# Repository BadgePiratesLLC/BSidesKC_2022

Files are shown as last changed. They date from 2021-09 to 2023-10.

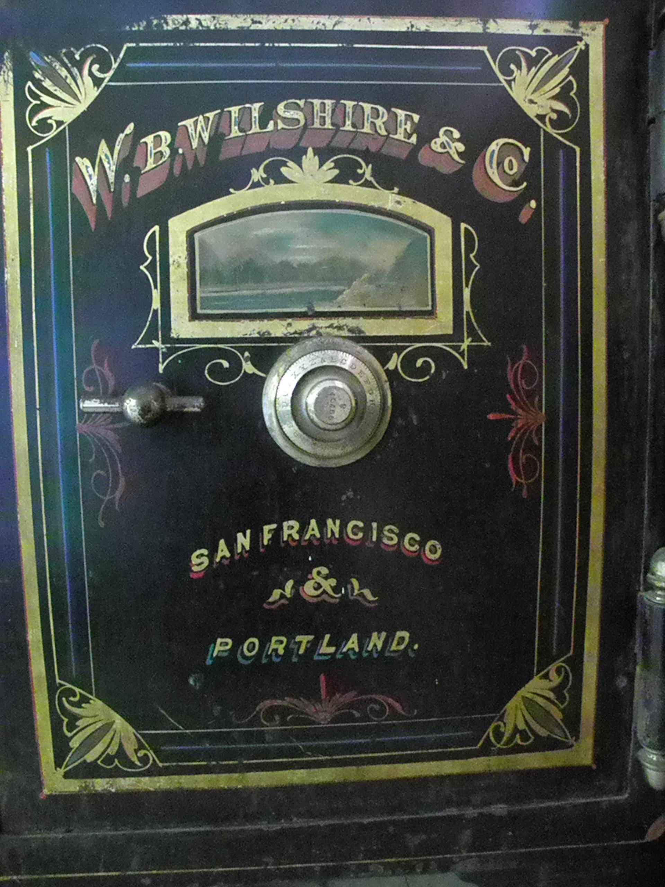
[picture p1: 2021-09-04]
Pic/Ao8DC.jpg

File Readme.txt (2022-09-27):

BSidesKC 2022 Website: https://bsideskc.org/

Date: September 23-24, 2021 | PlexPod Westport| Kansas City, MO

LED Layout
------------------
io03 - D1 - "B"
io34 - D2 - "S"
io04 - D3 - "I"
io33 - D4 - "D"
io05 - D5 - "E"
io26 - D6 - "S" (second S)
io06 - D7 - "0"
io21 - D8 - "1" 
io14 - D9 - "2"
io35 - D10 - "3"
io10 - D11 - "4"
io15 - D13 - "5"
io36 - D14 - "6"
io11 - D15 - "7"
io16 - D17 - "8"
io37 - D18 - "9"
io12 - D19 - "10"
io17 - D20 - "11"

Rotary A - 38
Rotary B - 13
Rotary Switch - 7

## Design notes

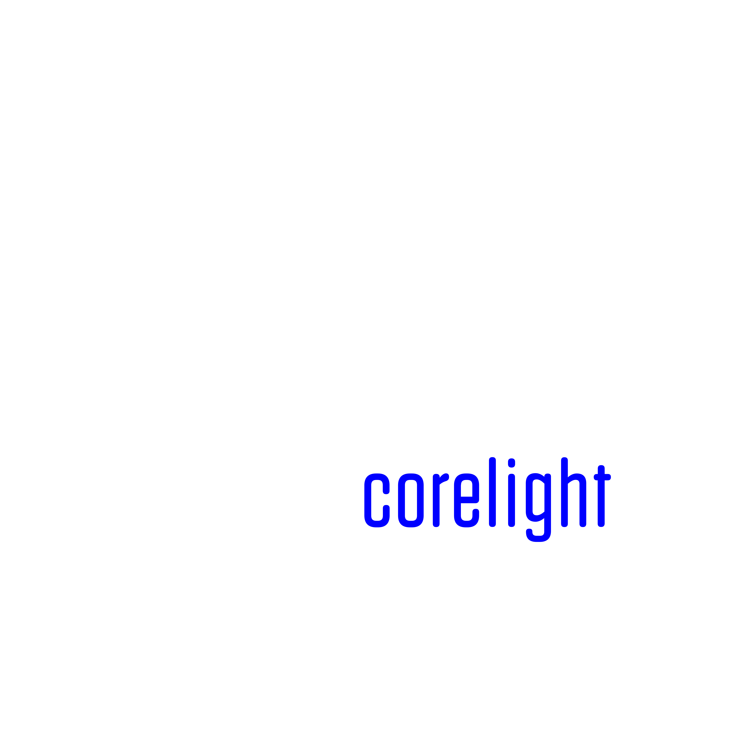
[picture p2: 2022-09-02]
CAD/Gold SAOs/Corelight/.svg2shenzhen-cache/images/F.SilkS_g2228.png

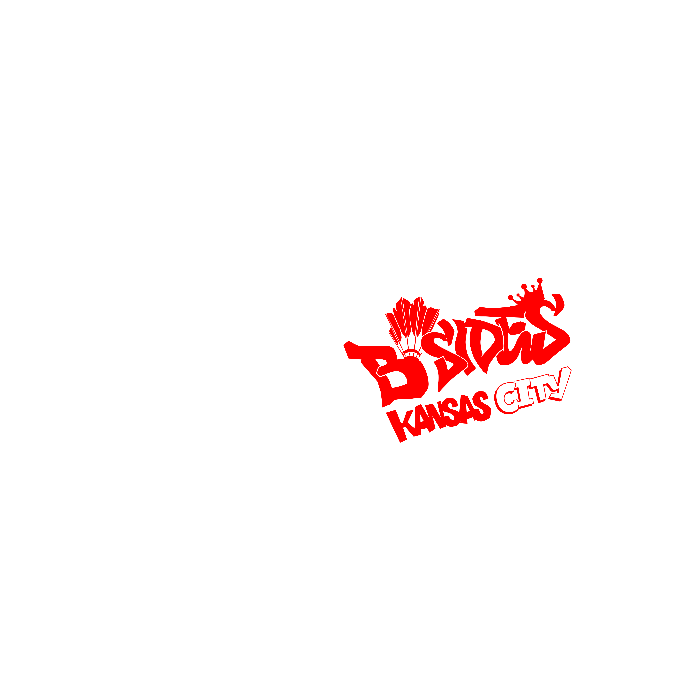
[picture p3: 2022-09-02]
CAD - Prototypes/BsidesKC 2022 SAO/.svg2shenzhen-cache/images/F.SilkS_g31527.png

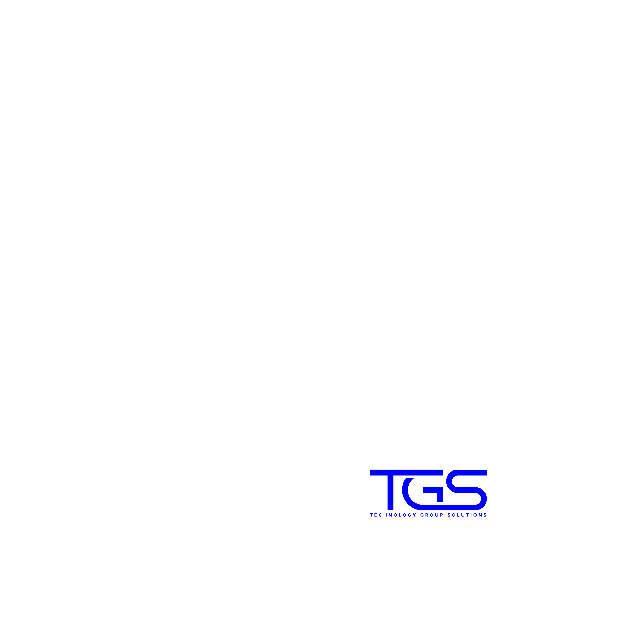
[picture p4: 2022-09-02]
CAD/Gold SAOs/Arista-TGS/.svg2shenzhen-cache/images/F.SilkS_g5244.png

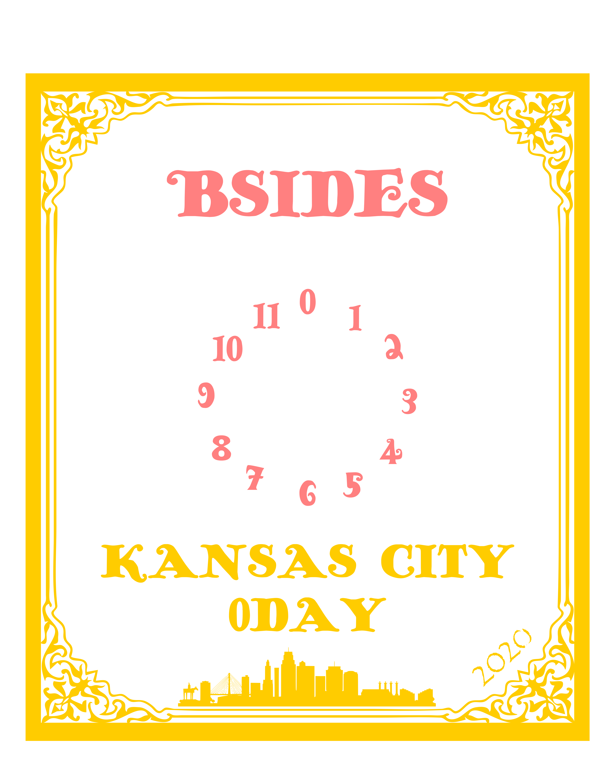
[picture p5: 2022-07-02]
CAD - Prototypes/.svg2shenzhen-cache/images/F.Mask_g1717.png

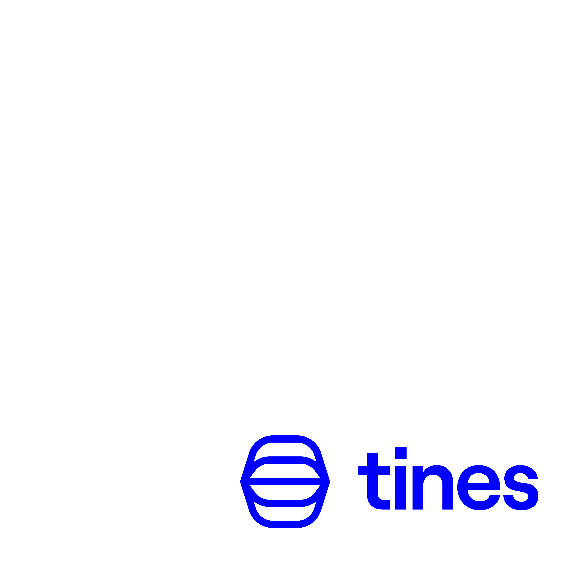
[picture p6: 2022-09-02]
CAD/Gold SAOs/Tines/.svg2shenzhen-cache/images/F.SilkS_g897.png

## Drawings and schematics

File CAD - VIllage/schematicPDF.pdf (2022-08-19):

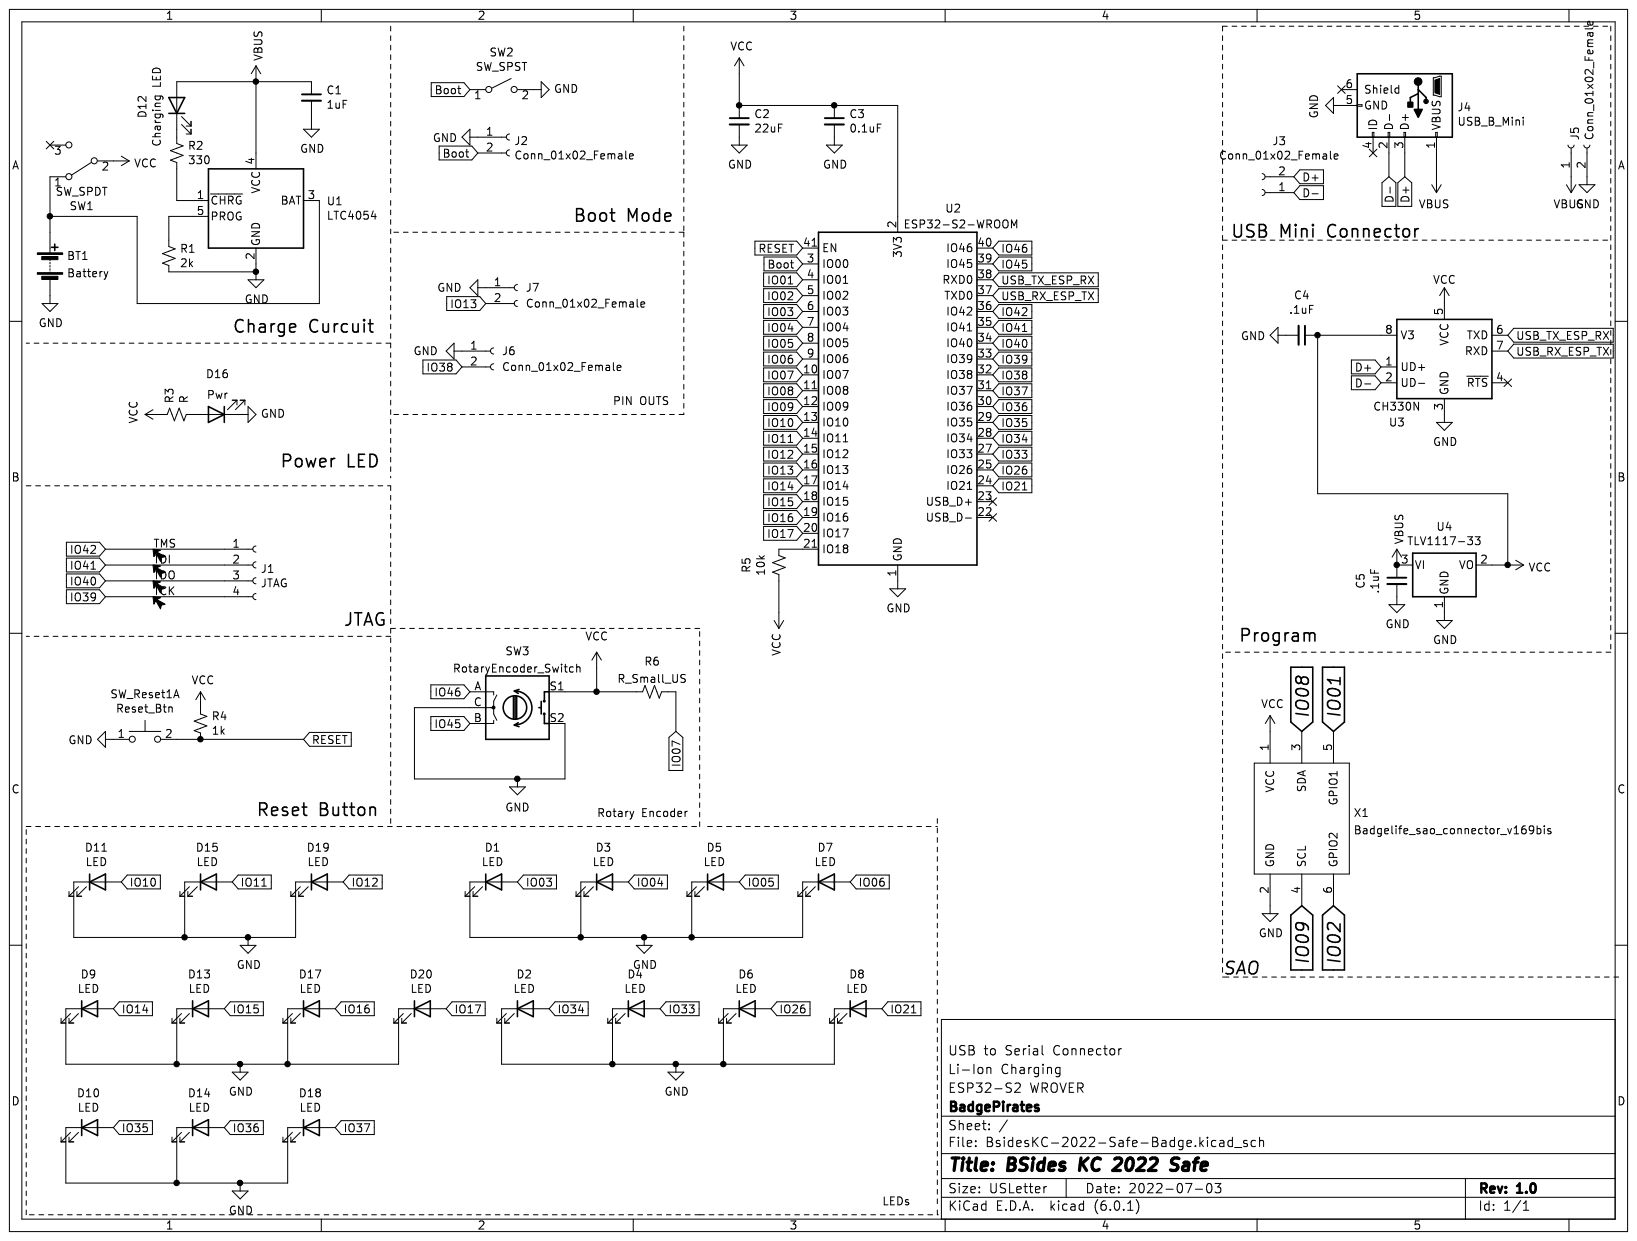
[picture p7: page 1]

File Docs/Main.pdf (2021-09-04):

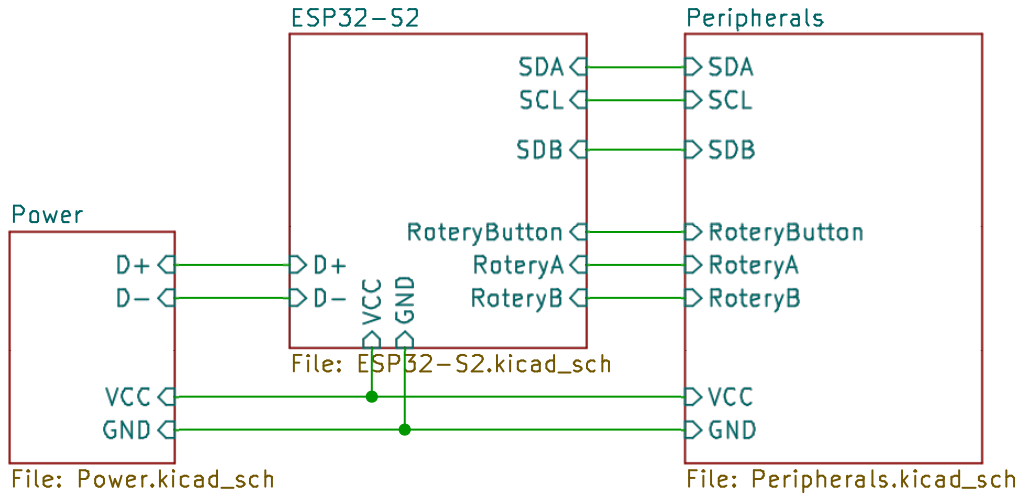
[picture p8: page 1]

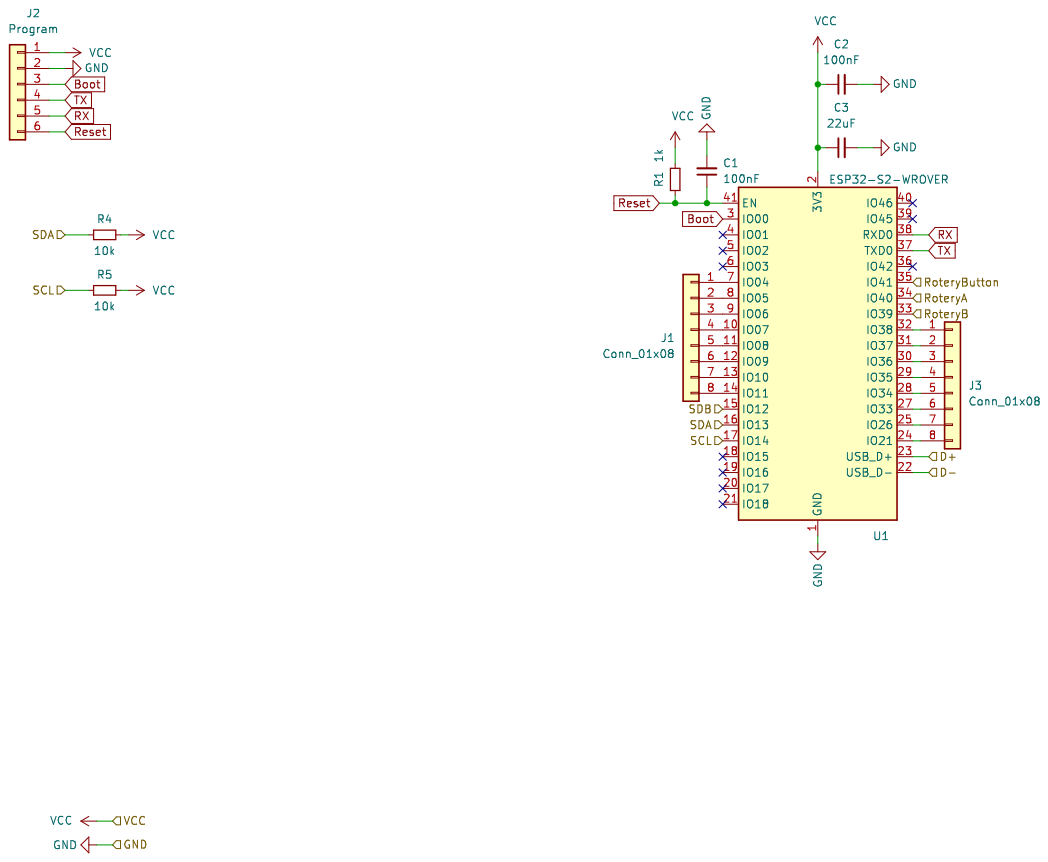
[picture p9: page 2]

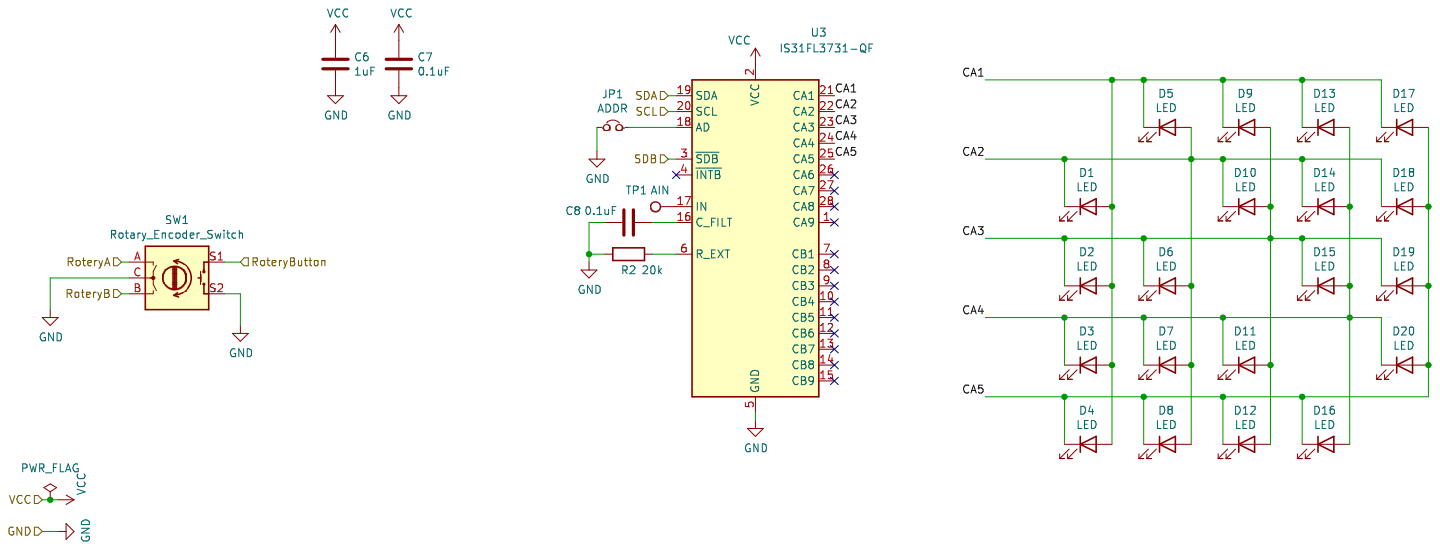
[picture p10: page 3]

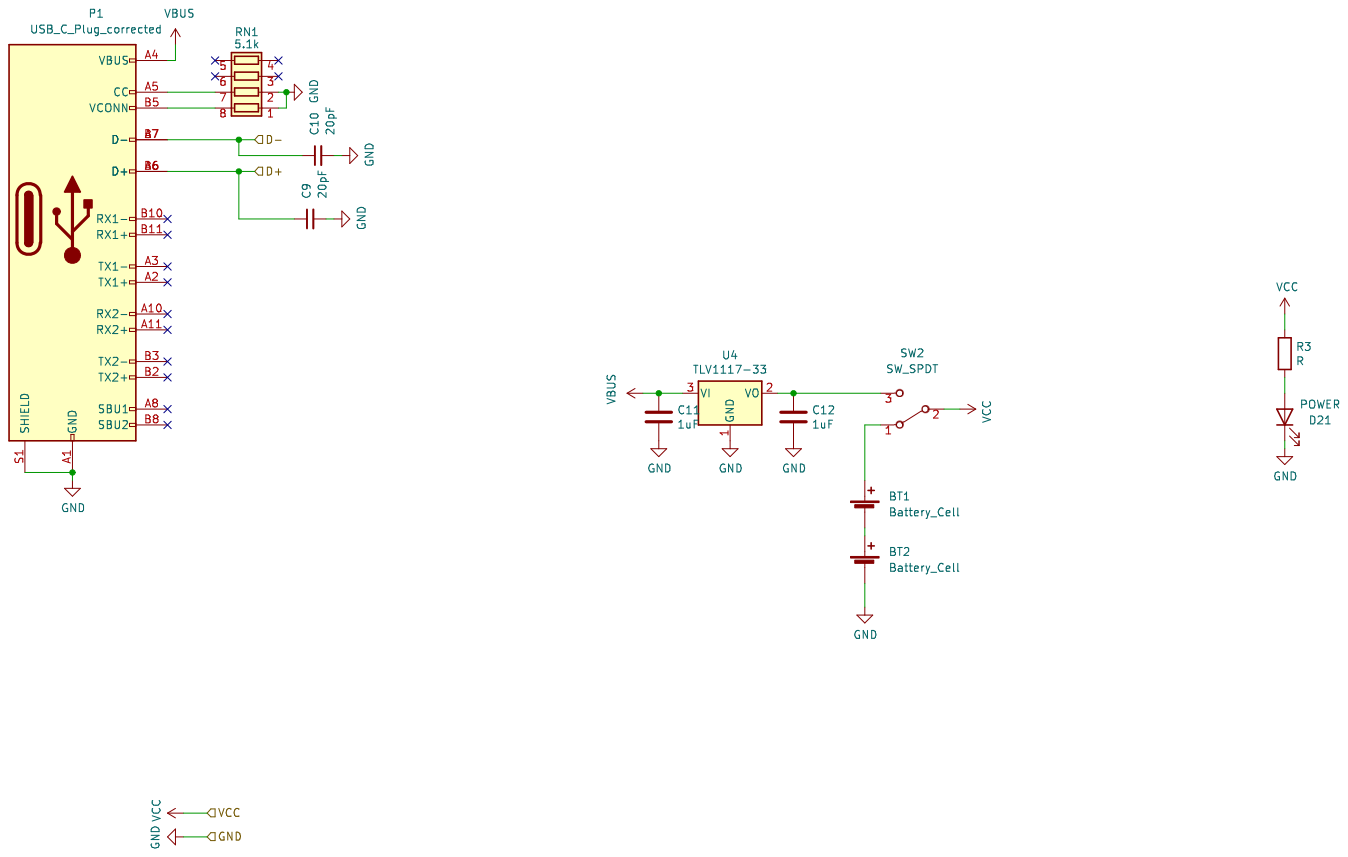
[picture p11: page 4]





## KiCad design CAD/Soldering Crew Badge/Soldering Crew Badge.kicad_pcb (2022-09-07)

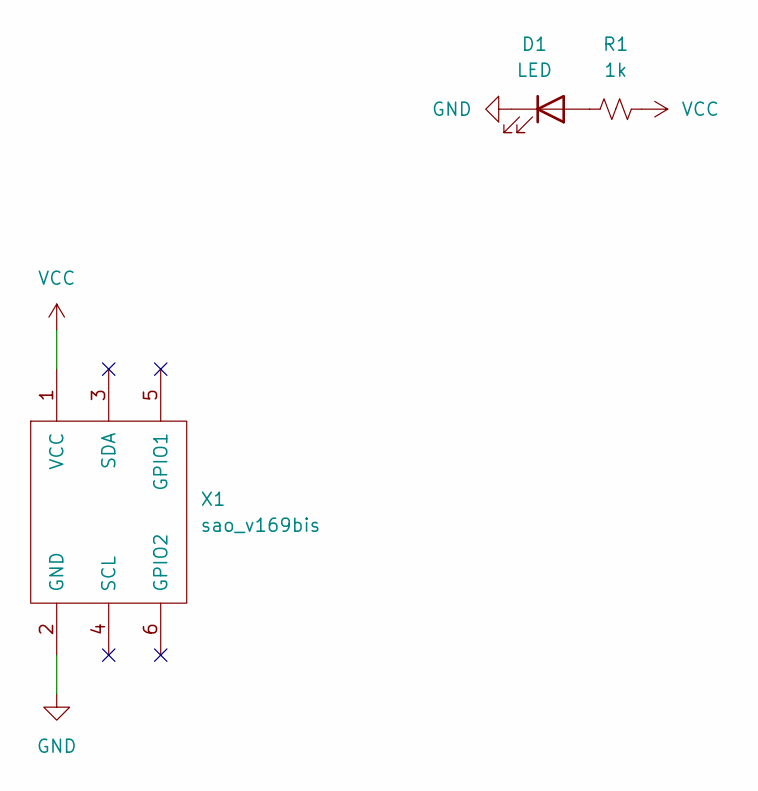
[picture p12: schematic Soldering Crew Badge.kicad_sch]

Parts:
D1: LED; LED_Osram_Lx_P47F_D2mm_ReverseMount_Proper_Mask Only
R1: 1k; R_1206_3216Metric
X1: sao_v169bis; Badgelife-SAOv169-SAO_Side_B.SLK

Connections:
GND: D1.1 (K), X1.2 (GND)
unnamed: D1.2 (A), R1.1
VCC: R1.2, X1.1 (VCC)

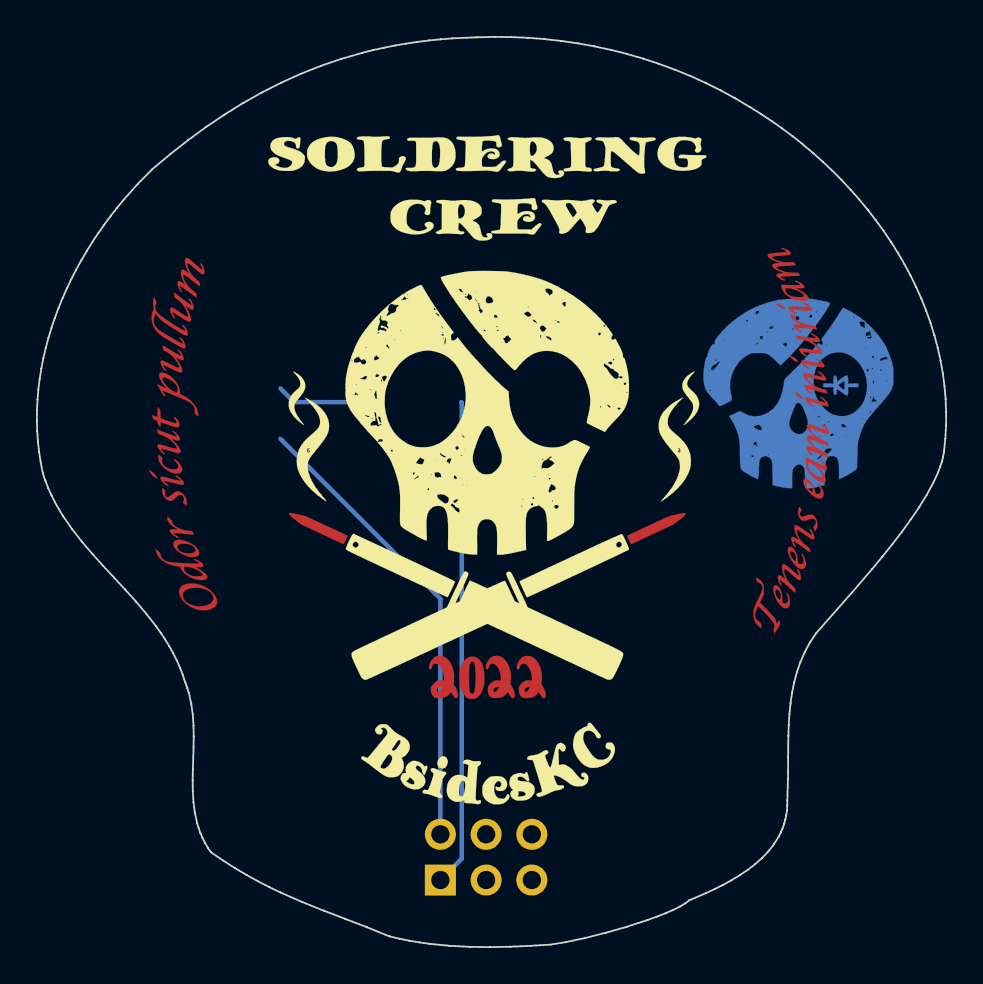
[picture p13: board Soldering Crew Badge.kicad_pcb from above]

Board: 2 copper layers, 50.5 x 50.6 mm, 3 parts (1 on the bottom side), 3 nets.

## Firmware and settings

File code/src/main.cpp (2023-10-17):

#include <Arduino.h>
#include <AsyncTCP.h>
#include <BfButton.h>
#include <EEPROM.h>
#include "WebServer.h"
#include <ESPAsyncWebServer.h>
#include <RotaryEncoder.h>
#include <WiFi.h>
#include <WebSerial.h>

#include "constants.hpp"
#include "hardware.hpp"
#include "ota.hpp"

static int pos = 0;
static int dir = 0;
static int currentNumber = 0;
static int lastNumber = 0;
int selectedBling = 0;

int inputPosition = 0;
int userInputLength = 7;
static int userInput[7] = {0, 0, 0, 0, 0, 0, 0};

static bool isCode0Unlocked = false;
static bool isCode1Unlocked = false;
static bool isCode2Unlocked = false;
static bool isCode3Unlocked = false;
static bool isCode4Unlocked = false;
static bool isCode5Unlocked = false;
static bool isCodeJennyUnlocked = false;

static String ssid = "BSidesKC-";
static String password = "";

OTA updater;

enum ProgramState
{
  BLING_MODE = 0,
  INPUT_MODE = 1
};

enum ProgramState previousState = INPUT_MODE;
enum ProgramState currentState = INPUT_MODE;

unsigned long previousTime = 0;
unsigned long currentTime = 0;
unsigned long lastWifiMsgTimeMs = 0;
int numIntervalsWithoutInput = 0;
bool hasInputChangedDuringInterval = false;
bool wifiSerialOn = false;

BfButton btn(BfButton::STANDALONE_DIGITAL, ROTARY_SWITCH, true, LOW);
BfButton bootbtn(BfButton::STANDALONE_DIGITAL, BOOT_BTN, true, LOW);

AsyncWebServer server(80);

// helper methods
// wraps both serial and web serial println methods 
// so we don't always have to call (or forget)
void SerialPrintln(String msg) {
  if (wifiSerialOn) {
    WebSerial.println(msg);
  }
  Serial.println(msg);
}

void SerialPrintln(int msg) {
  if (wifiSerialOn) {
    WebSerial.println(msg);
  }
  Serial.println(msg);
}

void SerialPrint(String msg) {
  if (wifiSerialOn) {
    WebSerial.print(msg);
  }
  Serial.print(msg);
}

void SerialPrint(int msg) {
  if (wifiSerialOn) {
    WebSerial.print(msg);
  }
  Serial.print(msg);
}

/* Message callback of WebSerial */
void recvMsg(uint8_t *data, size_t len) {
  String d = "";
  for(int i=0; i < len; i++){
    d += char(data[i]);
  }

  if (d.indexOf("help") != -1) {
    SerialPrintln("<< " + d);
    SerialPrintln(HELP_MSG + " " + JENNY_HELP_MSG);
  } else if (d.indexOf("credits")) {
    SerialPrintln("<< " + d);
    SerialPrintln(CREDITS_MSG);
  } else {  
    SerialPrintln("Received Data...");
    SerialPrintln(d);
  }

  lastWifiMsgTimeMs = millis();
}

void setupWifiSerial() {  
  if (password.length() == 0 && ssid.length() == 9) {
    Serial.println("Setting up wifi for the first time...");
    // we need a unique SSID and PW for each badge, use micros to get a random time offset for the PW
    delay(50);
    long time = micros();
    char passwordRaw[16];
    ltoa(time, passwordRaw, 10);
    // cast it as a string
    String password = String(passwordRaw);
    int passwordLength = password.length();
    // uuse the last 3 of the password for the ssid
    String uniqueSSID = password.substring(passwordLength-3, passwordLength);
    bool success = ssid.concat(uniqueSSID);
    password.concat("1");
    char SSID[ssid.length()+1];
    char PASSWORD[password.length()+1];
    
    ssid.toCharArray(SSID, ssid.length()+1);
    password.toCharArray(PASSWORD, password.length()+1);
    WiFi.mode(WIFI_AP);
    WiFi.softAP(SSID, PASSWORD);

    SerialPrint("SSID: ");
    SerialPrintln(SSID);
    SerialPrint("Password: ");
    SerialPrintln(PASSWORD);
    
    // save wifi password to eeprom
    EEPROM.writeString(WIFI_SSID_ADDR, SSID);
    EEPROM.writeString(WIFI_PASSWORD_ADDR, PASSWORD);
    EEPROM.commit();
  } else {
    SerialPrintln("Jenny is fixing the wifi...");
    int ssidLength = ssid.length() + 1;
    int passwordLength = password.length() + 1;
    char SSID[ssidLength];
    char PASSWORD[passwordLength];
    ssid.toCharArray(SSID, ssidLength);
    password.toCharArray(PASSWORD, passwordLength);
    WiFi.softAP(SSID, PASSWORD);

    SerialPrint("SSID: ");
    SerialPrintln(SSID);
    SerialPrint("Password: ");
    SerialPrintln(PASSWORD);
  }
  
  IPAddress IP = WiFi.softAPIP();
  Serial.println("Web Serial: http://" + IP.toString() + "/");
  WebSerial.begin(&server, "/");
  WebSerial.msgCallback(recvMsg);
  server.begin();
  wifiSerialOn = true;
  lastWifiMsgTimeMs = millis();
}

class Flasher
{
  // Class Member Variables
  // These are initialized at startup
  int ledPin = LED_B; // the number of the LED pin
  long OnTime = 25;   // milliseconds of on-time
  long OffTime = 25;  // milliseconds of off-time
  int interval = 25;
  int index = 0;
  const static int PATTERN_0_INDEX_MAX = 132;
  const static int PATTERN_1_INDEX_MAX = 24;

  int inputPattern0[PATTERN_0_INDEX_MAX][2] = {
      // bsides letters on then off in forward order
      {LED_B, HIGH},
      {LED_B, LOW},
      {LED_S1, HIGH},
      {LED_S1, LOW},
      {LED_I, HIGH},
      {LED_I, LOW},
      {LED_D, HIGH},
      {LED_D, LOW},
      {LED_E, HIGH},
      {LED_E, LOW},
      {LED_S2, HIGH},
      {LED_S2, LOW},
      // bsides letters on then off in backwards order
      {LED_S2, HIGH},
      {LED_S2, LOW},
      {LED_E, HIGH},
      {LED_E, LOW},
      {LED_D, HIGH},
      {LED_D, LOW},
      {LED_I, HIGH},
      {LED_I, LOW},
      {LED_S1, HIGH},
      {LED_S1, LOW},
      {LED_B, HIGH},
      {LED_B, LOW},
      // all the number leds on and off in forward order
      {LED_0, HIGH},
      {LED_0, LOW},
      {LED_1, HIGH},
      {LED_1, LOW},
      {LED_2, HIGH},
      {LED_2, LOW},
      {LED_3, HIGH},
      {LED_3, LOW},
      {LED_4, HIGH},
      {LED_4, LOW},
      {LED_5, HIGH},
      {LED_5, LOW},
      {LED_6, HIGH},
      {LED_6, LOW},
      {LED_7, HIGH},
      {LED_7, LOW},
      {LED_8, HIGH},
      {LED_8, LOW},
      {LED_9, HIGH},
      {LED_9, LOW},
      {LED_10, HIGH},
      {LED_10, LOW},
      {LED_11, HIGH},
      {LED_11, LOW},
      // all the number leds on then off in backwards order
      {LED_11, HIGH},
      {LED_11, LOW},
      {LED_10, HIGH},
      {LED_10, LOW},
      {LED_9, HIGH},
      {LED_9, LOW},
      {LED_8, HIGH},
      {LED_8, LOW},
      {LED_7, HIGH},
      {LED_7, LOW},
      {LED_6, HIGH},
      {LED_6, LOW},
      {LED_5, HIGH},
      {LED_5, LOW},
      {LED_4, HIGH},
      {LED_4, LOW},
      {LED_3, HIGH},
      {LED_3, LOW},
      {LED_2, HIGH},
      {LED_2, LOW},
      {LED_1, HIGH},
      {LED_1, LOW},
      {LED_0, HIGH},
      {LED_0, LOW},
      // light up all the letters then turn them all off in reverse order
      {LED_B, HIGH},
      {LED_S1, HIGH},
      {LED_I, HIGH},
      {LED_D, HIGH},
      {LED_E, HIGH},
      {LED_S2, HIGH},
      {LED_S2, LOW},
      {LED_E, LOW},
      {LED_D, LOW},
      {LED_I, LOW},
      {LED_S1, LOW},
      {LED_B, LOW},
      // light up all the numbers in order then turn them all off in reverse order
      {LED_0, HIGH},
      {LED_1, HIGH},
      {LED_2, HIGH},
      {LED_3, HIGH},
      {LED_4, HIGH},
      {LED_5, HIGH},
      {LED_6, HIGH},
      {LED_7, HIGH},
      {LED_8, HIGH},
      {LED_9, HIGH},
      {LED_10, HIGH},
      {LED_11, HIGH},
      {LED_11, LOW},
      {LED_10, LOW},
      {LED_9, LOW},
      {LED_8, LOW},
      {LED_7, LOW},
      {LED_6, LOW},
      {LED_5, LOW},
      {LED_4, LOW},
      {LED_3, LOW},
      {LED_2, LOW},
      {LED_1, LOW},
      {LED_0, LOW}};

  int inputPattern1[PATTERN_1_INDEX_MAX][2] = {
      // bsides letters on then off in forward order
      {LED_B, HIGH},
      {LED_B, LOW},
      {LED_S1, HIGH},
      {LED_S1, LOW},
      {LED_I, HIGH},
      {LED_I, LOW},
      {LED_D, HIGH},
      {LED_D, LOW},
      {LED_E, HIGH},
      {LED_E, LOW},
      {LED_S2, HIGH},
      {LED_S2, LOW},
      // bsides letters on then off in backwards order
      {LED_S2, HIGH},
      {LED_S2, LOW},
      {LED_E, HIGH},
      {LED_E, LOW},
      {LED_D, HIGH},
      {LED_D, LOW},
      {LED_I, HIGH},
      {LED_I, LOW},
      {LED_S1, HIGH},
      {LED_S1, LOW},
      {LED_B, HIGH},
      {LED_B, LOW},
  };

  // These maintain the current state
  int ledState;                 // ledState used to set the LED
  unsigned long previousMillis; // will store last time LED was updated

  // Constructor - creates a Flasher
  // and initializes the member variables and state
public:
  Flasher()
  {
    ledState = LOW;
    previousMillis = 0;
  }

  void Update(unsigned long currentMillis)
  {

    switch (selectedBling)
    {
    case 0:
      // check to see if it's time to change the state of the LED
      ledPin = inputPattern0[index][0];
      ledState = inputPattern0[index][1];

      if ((currentMillis - previousMillis >= OffTime))
      {
        digitalWrite(ledPin, ledState); // Update the actual LED
        previousMillis = currentMillis; // Remember the time
        index += 1;                     // update the
        if (index >= PATTERN_0_INDEX_MAX)
        { // reset index after the end of the array
          index = 0;
          sleep();
        }
      }
      break;
    case 1:
      // check to see if it's time to change the state of the LED
      ledPin = inputPattern1[index][0];
      ledState = inputPattern1[index][1];

      if ((currentMillis - previousMillis >= OffTime))
      {
        digitalWrite(ledPin, ledState); // Update the actual LED
        previousMillis = currentMillis; // Remember the time
        index += 1;                     // update the
        if (index >= PATTERN_1_INDEX_MAX)
        { // reset index after the end of the array
          index = 0;
          sleep();
        }
      }
    }
  }
};

Flasher led1 = Flasher();
// Setup a RotaryEncoder with 2 steps per latch for the 2 signal input pins:
RotaryEncoder encoder(PIN_IN1, PIN_IN2, RotaryEncoder::LatchMode::TWO03);

void handleBlingChange()
{
  if (selectedBling >= NUM_BLING - 1)
  {
    selectedBling = 0;
  }
  else
  {
    selectedBling++;
  }
}

void resetUserInput()
{
  inputPosition = 0;
  for (int i = 0; i < userInputLength; i++)
  {
    userInput[i] = 0;
  }
}

// TODO can probably make this better ;) 
void checkIsValidCode()
{
  boolean isCode0 = true;
  boolean isCode1 = true;
  boolean isCode2 = true;
  boolean isCode3 = true;
  boolean isCode4 = true;
  boolean isCode5 = true;
  boolean isCodeJenny = true;
  boolean isCodeReset = true;

  int i = 0;
  //Check code 1
  while (i < userInputLength && isCode0)
  {
    isCode0 = userInput[i] == CODE_0[i];
    i++;
  }

  i = 0;
  while (i < userInputLength && isCodeJenny)
  {
    isCodeJenny = userInput[i] == CODE_JENNY[i];
    i++;
  }

  i = 0;
  while (i < userInputLength && isCodeReset)
  {
    isCodeReset = userInput[i] == CODE_RESET[i];
    i++;
  }

  i = 0;
  while (i < userInputLength && isCode1)
  {
    isCode1 = userInput[i] == CODE_1[i];
    i++;
  }

  i = 0;
  while (i < userInputLength && isCode2)
  {
    isCode2 = userInput[i] == CODE_2[i];
    i++;
  }

  i = 0;
  while (i < userInputLength && isCode3)
  {
    isCode3 = userInput[i] == CODE_3[i];
    i++;
  }

  i = 0;
  while (i < userInputLength && isCode4)
  {
    isCode4 = userInput[i] == CODE_4[i];
    i++;
  }

  i = 0;
  while (i < userInputLength && isCode5)
  {
    isCode5 = userInput[i] == CODE_5[i];
    i++;
  }

  if (isCodeReset) {
    Serial.println("Resetting EEPROM");
    isCode0Unlocked = false;
    isCode1Unlocked = false;
    isCode2Unlocked = false;
    isCode3Unlocked = false;
    isCode4Unlocked = false;
    isCode5Unlocked = false;
    EEPROM.writeBool(CODE_0_ADDR, false);
    EEPROM.writeBool(CODE_1_ADDR, false);
    EEPROM.writeBool(CODE_2_ADDR, false);
    EEPROM.writeBool(CODE_3_ADDR, false);
    EEPROM.writeBool(CODE_4_ADDR, false);
    EEPROM.writeBool(CODE_5_ADDR, false);
    EEPROM.writeBool(CODE_JENNY_ADDR, false);
    EEPROM.writeString(WIFI_SSID_ADDR, "");
    EEPROM.writeString(WIFI_PASSWORD_ADDR, "");
    EEPROM.commit();
    confirmationFlash();
    resetUserInput();
  }

  else if (isCode0)
  {
    isCode0Unlocked = true;
    EEPROM.writeBool(CODE_0_ADDR, isCode0Unlocked);
    Serial.println("CODE 0 MATCHES");
    confirmationFlash();
    resetUserInput();
  }

  else if (isCodeJenny)
  {
    isCodeJennyUnlocked = true;
    EEPROM.writeBool(CODE_JENNY_ADDR, isCodeJennyUnlocked);
    Serial.println("CODE JENNY TYPED IN");
    setupWifiSerial();
    confirmationFlash();
  }

  else if(isCode1){
    isCode1Unlocked = true;
    EEPROM.writeBool(CODE_1_ADDR, isCode1Unlocked);
    Serial.print("CODE 1 MATCHES");
    confirmationFlash();
    resetUserInput();
  }
  
  else if(isCode2){
    isCode2Unlocked = true;
    EEPROM.writeBool(CODE_2_ADDR, isCode2Unlocked);
    Serial.println("CODE 2 MATCHES");
    confirmationFlash();
    resetUserInput();
  }

  else if(isCode3){
    isCode3Unlocked = true;
    EEPROM.writeBool(CODE_3_ADDR, isCode3Unlocked);
    Serial.println("CODE 3 MATCHES");
    confirmationFlash();
    resetUserInput();
  }

  else if(isCode4){
    isCode4Unlocked = true;
    EEPROM.writeBool(CODE_4_ADDR, isCode4Unlocked);
    Serial.println("CODE 4 MATCHES");
    confirmationFlash();
    resetUserInput();
  }

  else if(isCode5){
    isCode5Unlocked = true;
    EEPROM.writeBool(CODE_5_ADDR, isCode5Unlocked);
    Serial.println("CODE 5 MATCHES");
    confirmationFlash();
  } else {
    Serial.println("INVALID CODE");
    if(inputPosition>=6){
      errorFlash();
      resetUserInput();
    }
  }

  if (isCode0 || isCode1 || isCode2 || isCode3 || isCode4 || isCode5 || isCodeJennyUnlocked) {
    EEPROM.commit();
  }

}

void logCode()
{
  // Do confirmation animation
  turnOffNumber(currentNumber);
  delay(50);
  turnOnNumber(currentNumber);

  SerialPrint("User Input: ");
  for (int i = 0; i < userInputLength; i++)
  {
    SerialPrint(userInput[i]);
  }
  SerialPrintln("");
}

void pressHandler(BfButton *btn, BfButton::press_pattern_t pattern)
{
  switch (pattern)
  {
  case BfButton::SINGLE_PRESS:
    if (currentState == BLING_MODE)
    {
      handleBlingChange();
    }
    else
    {
      numIntervalsWithoutInput = 0;
      userInput[inputPosition] = currentNumber;
      logCode();
      checkIsValidCode();
      if (inputPosition < userInputLength)
      {
        inputPosition++;
      }
      else
      {
        resetUserInput();
      }
    }
    break;

  case BfButton::DOUBLE_PRESS:
    Serial.println("Double push");
    break;

  case BfButton::LONG_PRESS:
    Serial.println("Long push");
    break;
  }
}

void bootpressHandler(BfButton *btn, BfButton::press_pattern_t pattern)
{
  switch (pattern)
  {
  case BfButton::DOUBLE_PRESS:
    Serial.println("Entering OTA Update mode");
    turnOffAllLights();
    updater.checkOTASync();
    break;
  }
}

// Read the current position of the encoder and print out when changed.
void readEncoder()
{
  int newPos = encoder.getPosition();
  int newDir = (int)(encoder.getDirection());
  // my board (pecord) has the encoder wired backwards
  // instead of fixing the solder I "fixed" it in code
  // if its going backwards for you flip that flagoh
  if (INVERT_DIR)
  {
    newDir *= -1;
  }

  // save off the previous number
  lastNumber = currentNumber;
  // get the new number
  currentNumber += newDir;
  if (currentNumber > ROTARYMAX)
  {
    currentNumber = ROTARYMIN;
  }
  else if (currentNumber < ROTARYMIN)
  {
    currentNumber = ROTARYMAX;
  }

  if (pos != newPos)
  {
    pos = newPos;
  }

  if (DEBUG && VERBOSE)
  {
    Serial.print("pos:");
    Serial.print(newPos);
    Serial.print(" dir:");
    Serial.println(newDir);
  }
}

// TODO copied from BlinkyLights.ino - ghetto, needs clean up, don't use delay, blocks for five seconds
void blingMode(unsigned long currentTime)
{
  if (currentState == BLING_MODE && previousState != BLING_MODE)
  {
    resetUserInput();
    turnOffAllLights();
    if (DEBUG) {
      Serial.println("doing bling mode stuffz");
    }
  }
  led1.Update(currentTime);
}

void updateNumber(int lastNumber, int currentNumber)
{
  turnOffNumber(lastNumber);
  turnOnNumber(currentNumber);
}

bool hasInputChanged()
{
  readEncoder();
  if (lastNumber != currentNumber)
    return true;
  return false;
}

// TODO see about using interupts for detecting when the input changes
void inputMode(bool hasInputChanged)
{
  if(isCode0Unlocked) {
    digitalWrite(LED_B, HIGH);
  }

  if(isCode1Unlocked) {
    digitalWrite(LED_S1, HIGH);
  }

  if(isCode2Unlocked) {
    digitalWrite(LED_I, HIGH);
  }

  if(isCode3Unlocked) {
    digitalWrite(LED_D, HIGH);
  }

  if(isCode4Unlocked) {
    digitalWrite(LED_E, HIGH);
  }

  if(isCode5Unlocked) {
    digitalWrite(LED_S2, HIGH);
  }

  if (currentState == INPUT_MODE && previousState == BLING_MODE)
  {
    turnOffAllLights();
    if (DEBUG) {
      Serial.println("doing input mode stuffz");
    }
  }

  // currently handles spinning the encoder knob and updating the numbers
  // needs to also "save" off the number when they press the button
  if (hasInputChanged)
  {
    updateNumber(lastNumber, currentNumber);
  }


}

IRAM_ATTR void checkPosition()
{
  encoder.tick(); // just call tick() to check the state.
}

void setup()
{
  EEPROM.begin(512);
  Serial.begin(115200);
  encoder.setPosition(0 / ROTARYSTEPS);
  pullDownAllPins();
  turnOffAllLights();

  // register interrupt routine
  attachInterrupt(digitalPinToInterrupt(PIN_IN1), checkPosition, CHANGE);
  attachInterrupt(digitalPinToInterrupt(PIN_IN2), checkPosition, CHANGE);

  // Butt stuff
  // Button settings
  btn.onPress(pressHandler)
      .onDoublePress(pressHandler)     // default timeout
      .onPressFor(pressHandler, 1000); // custom timeout for 1 second
  
  bootbtn.onDoublePress(bootpressHandler);     // default timeout
      

  isCode0Unlocked = EEPROM.readBool(CODE_0_ADDR);  
  isCode1Unlocked = EEPROM.readBool(CODE_1_ADDR);
  isCode2Unlocked = EEPROM.readBool(CODE_2_ADDR);  
  isCode3Unlocked = EEPROM.readBool(CODE_3_ADDR);  
  isCode4Unlocked = EEPROM.readBool(CODE_4_ADDR);  
  isCode5Unlocked = EEPROM.readBool(CODE_5_ADDR);
  isCodeJennyUnlocked = EEPROM.readBool(CODE_JENNY_ADDR);

  String savedWifiSSID = EEPROM.readString(WIFI_SSID_ADDR);
  String savedWifiPwd = EEPROM.readString(WIFI_PASSWORD_ADDR);
  if (savedWifiPwd.length() > 0) {
    if (DEBUG) {
      Serial.print("Found existing wifi creds");
      Serial.print("SSID: ");
      Serial.println(savedWifiSSID);
      Serial.print("Password: ");
      Serial.println(savedWifiPwd);
    }
    ssid = savedWifiSSID;
    password = savedWifiPwd;
  }

  if (DEBUG) {
    Serial.print("isCode0Unlocked: ");
    Serial.println(isCode0Unlocked ? "true" : "false");
    Serial.print("isCode1Unlocked: ");
    Serial.println(isCode1Unlocked ? "true" : "false");
    Serial.print("isCode2Unlocked: ");
    Serial.println(isCode2Unlocked ? "true" : "false");
    Serial.print("isCode3Unlocked: ");
    Serial.println(isCode3Unlocked ? "true" : "false");
    Serial.print("isCode5Unlocked: ");
    Serial.println(isCode5Unlocked ? "true" : "false");
    Serial.print("isCode4Unlocked: ");
    Serial.println(isCode4Unlocked ? "true" : "false");
    Serial.print("isCodeJennyUnlocked: ");
    Serial.println(isCodeJennyUnlocked ? "true" : "false");
  }

  SerialPrintln(HELP_MSG);
  if (isCodeJennyUnlocked) {
    setupWifiSerial();
  } else {
    SerialPrintln(JENNY_HELP_MSG);
  }

  if (isCode0Unlocked || isCode2Unlocked || isCode3Unlocked || isCode4Unlocked || isCode5Unlocked || isCodeJennyUnlocked) {
    SerialPrintln(SPACE_BALLS_MSG);
  }

}

void loop() {
  encoder.tick();
  btn.read();
  bootbtn.read();

  previousState = currentState;
  currentTime = millis();
  bool inputChanged = hasInputChanged();

  if (inputChanged)
  {
    hasInputChangedDuringInterval = true;
  }

  // TODO move into a timer instead of doing it in the main loop
  // and/or look into using the encoder.getMillisBetweenRotations function
  if ((currentTime - previousTime) >= INTERVAL)
  {
    previousTime = currentTime;

    if (hasInputChangedDuringInterval)
    {
      hasInputChangedDuringInterval = false;
      numIntervalsWithoutInput = 0;
    }
    else
    {
      numIntervalsWithoutInput += 1;
    }
  }

  // if we go so long without any input fallback to bling mode
  if (numIntervalsWithoutInput >= BLING_MODE_TIMEOUT_INTERVAL)
  {
    currentState = BLING_MODE;
  }
  else
  {
    currentState = INPUT_MODE;
  }

  if (DEBUG && previousState != currentState)
  {
    Serial.print("Interval time has passed: ");
    Serial.print(INTERVAL);
    Serial.print("ms, hasInputChangedDuringInterval: ");
    Serial.print(hasInputChangedDuringInterval ? "true" : "false");
    Serial.print(", numIntervalsWithoutInput: ");
    Serial.print(numIntervalsWithoutInput);
    Serial.print(", current state: ");
    Serial.println(currentState == INPUT_MODE ? "input mode" : "bling mode");
  }

  // two states to start - "bling" mode and "input" mode
  // if the input hasn't changed for a second or two go into bling mode
  // once the knob moves, come out of bling mode into input mode

  // ghetto state machine
  switch (currentState)
  {
  case BLING_MODE:
    blingMode(currentTime);
    break;
  case INPUT_MODE:
    inputMode(inputChanged);
    break;
  default:
    inputMode(inputChanged);
  }

  if (isCodeJennyUnlocked && lastWifiMsgTimeMs != 0) {
    unsigned long timeSinceLastWifiMsgInMs = millis() - lastWifiMsgTimeMs;
    if (timeSinceLastWifiMsgInMs >= 60000 && wifiSerialOn) { 
      SerialPrintln("Last message recieved on wifi more than one minute ago, turning off wifi, you can reset the badge to turn it back on.");
      WiFi.disconnect(true);
      server.end();
      wifiSerialOn = false;
    }
  }
}

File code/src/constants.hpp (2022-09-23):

#pragma once

#include <Arduino.h>

const int version = 3;

const int LED_B = 3;
const int LED_S1 = 34;
const int LED_I = 4;
const int LED_D = 33;
const int LED_E = 5;
const int LED_S2 = 26;

const int LED_0 = 6;
const int LED_1 = 21;
const int LED_2 = 14;
const int LED_3 = 35;
const int LED_4 = 10;
const int LED_5 = 15;
const int LED_6 = 36;
const int LED_7 = 11;
const int LED_8 = 16;
const int LED_9 = 37;
const int LED_10 = 12;
const int LED_11 = 17;

// in case patrick's rotary switch breaks
// const unsigned int ROTARY_SWITCH = GPIO_NUM_0;
const unsigned int ROTARY_SWITCH = GPIO_NUM_7;
const unsigned int BOOT_BTN = GPIO_NUM_0;

const bool DEBUG = false;
const bool VERBOSE = false;
const bool INVERT_DIR = true;
const int INTERVAL = 500;                  // ms
const int BLING_MODE_TIMEOUT_INTERVAL = 6; // 500ms * 2  = ~one seconds

const int PIN_IN1 = 13;
const int PIN_IN2 = 38;
const int ROTARYSTEPS = 1;
const int ROTARYMIN = 0;
const int ROTARYMAX = 11;
const int NUM_BLING = 2;

const int CODE_0_ADDR = 0;
const int CODE_1_ADDR = 1;
const int CODE_2_ADDR = 2;
const int CODE_3_ADDR = 3;
const int CODE_4_ADDR = 4;
const int CODE_5_ADDR = 5;
const int CODE_JENNY_ADDR = 6;

// leave space because we are saving strings? I dunno how it works
const int WIFI_SSID_ADDR = 50;
const int WIFI_PASSWORD_ADDR = 30;

const int CODE_0[7] = {3, 1, 4, 1, 5, 9, 2}; // pi
const int CODE_1[7] = {1, 2, 3, 4, 5, 0 ,0}; // space balls
const int CODE_2[7] = {4, 2, 0, 0, 0, 0, 0}; // 42
const int CODE_3[7] = {1, 7, 2, 0, 0, 0, 0}; // 172
const int CODE_4[7] = {1, 3, 3, 7, 0, 0, 0}; // leet
const int CODE_5[7] = {6, 6, 6, 0, 0, 0, 0}; // mark of the devil
const int CODE_RESET[7] = {1, 1, 1, 1, 1, 1}; // reset
const int CODE_JENNY[7] = {8, 6, 7, 5, 3, 0, 9};

const int allLeds[18] = {LED_0, LED_1,LED_2,LED_3,LED_4,LED_5,LED_6,LED_7,LED_8,LED_9,LED_10,LED_11,LED_B,LED_S1,LED_I,LED_D,LED_E,LED_S2};

const String HELP_MSG = "Thank you for coming to BSidesKC and hacking on the badge. ";
const String JENNY_HELP_MSG = "If the wifi isn't working try calling jenny.";
const String CREDITS_MSG = "Building badges for fun not profit, this badge was brought to you by rixon, networkgeek, pecord, icona_p0p, JiggleBilly, MrARM, fg and Codexmafia.";
const String SPACE_BALLS_MSG = "Next hint is _JNGI1dI-e8";

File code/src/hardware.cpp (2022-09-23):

#include "hardware.hpp"

void sleep() {
  esp_sleep_enable_timer_wakeup(1000000); // one second in microseconds
  esp_light_sleep_start();
}

void turnOffAllLights()
{
  
  for (int i = 0; i < 18; i++) {
    digitalWrite(allLeds[i], LOW);
  }
}

void turnOnAllLights()
{
  for (int i = 0; i < 18; i++) {
    digitalWrite(allLeds[i], HIGH);
  }
}

// Setup LEDS
void pullDownAllPins()
{
  pinMode(LED_B, OUTPUT);
  pinMode(LED_S1, OUTPUT);
  pinMode(LED_I, OUTPUT);
  pinMode(LED_D, OUTPUT);
  pinMode(LED_E, OUTPUT);
  pinMode(LED_S2, OUTPUT);
  pinMode(LED_0, OUTPUT);
  pinMode(LED_1, OUTPUT);
  pinMode(LED_2, OUTPUT);
  pinMode(LED_3, OUTPUT);
  pinMode(LED_4, OUTPUT);
  pinMode(LED_5, OUTPUT);
  pinMode(LED_6, OUTPUT);
  pinMode(LED_7, OUTPUT);
  pinMode(LED_8, OUTPUT);
  pinMode(LED_9, OUTPUT);
  pinMode(LED_10, OUTPUT);
  pinMode(LED_11, OUTPUT);
}

void turnOffNumber(int numeral)
{
  switch (numeral)
  {
  case 0:
    digitalWrite(LED_0, LOW);
    break;
  case 1:
    digitalWrite(LED_1, LOW);
    break;
  case 2:
    digitalWrite(LED_2, LOW);
    break;
  case 3:
    digitalWrite(LED_3, LOW);
    break;
  case 4:
    digitalWrite(LED_4, LOW);
    break;
  case 5:
    digitalWrite(LED_5, LOW);
    break;
  case 6:
    digitalWrite(LED_6, LOW);
    break;
  case 7:
    digitalWrite(LED_7, LOW);
    break;
  case 8:
    digitalWrite(LED_8, LOW);
    break;
  case 9:
    digitalWrite(LED_9, LOW);
    break;
  case 10:
    digitalWrite(LED_10, LOW);
    break;
  case 11:
    digitalWrite(LED_11, LOW);
    break;
  default:
    break;
  }
}

// TODO make a lookup table for the numeral -> LED_X
void turnOnNumber(int numeral)
{
  switch (numeral)
  {
  case 0:
    digitalWrite(LED_0, HIGH);
    break;
  case 1:
    digitalWrite(LED_1, HIGH);
    break;
  case 2:
    digitalWrite(LED_2, HIGH);
    break;
  case 3:
    digitalWrite(LED_3, HIGH);
    break;
  case 4:
    digitalWrite(LED_4, HIGH);
    break;
  case 5:
    digitalWrite(LED_5, HIGH);
    break;
  case 6:
    digitalWrite(LED_6, HIGH);
    break;
  case 7:
    digitalWrite(LED_7, HIGH);
    break;
  case 8:
    digitalWrite(LED_8, HIGH);
    break;
  case 9:
    digitalWrite(LED_9, HIGH);
    break;
  case 10:
    digitalWrite(LED_10, HIGH);
    break;
  case 11:
    digitalWrite(LED_11, HIGH);
    break;
  default:
    break;
  }
}

void confirmationFlash() {
  turnOffAllLights();
  delay(50);
  turnOnAllLights();
  delay(50);
  turnOffAllLights();
  delay(50);
  turnOnAllLights();
  delay(50);
  turnOffAllLights();
  turnOffAllLights();
  delay(50);
  turnOnAllLights();
  delay(50);
  turnOffAllLights();
  delay(50);
  turnOnAllLights();
  delay(50);
  turnOffAllLights();
}

void errorFlash(){
    turnOnAllLights();
    delay(2000);
    turnOffAllLights();
}

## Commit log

2021-09-27 adding S2 Files
    [Aragorn-32-S2.csv, Aragorn-32-S2.kicad_pcb, Aragorn-32-S2.kicad_sch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]
2022-07-02 Artwork updated + CAD Export
    Reformated artwork + resize
    Exported to CAD
    [BsidesKC-2022-Safe-Badge.kicad_pcb]
2022-07-04 adding and taking away
    Adding electronics to boards, and removing old builds.
    [8266-dev-B_Cu.gbr, 8266-dev-B_Mask.gbr, 8266-dev-B_SilkS.gbr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]
2022-08-17 fixing footprint and fill
    [BsidesKC-2022-Safe-Badge.kicad_pcb, BsidesKC-2022-Safe-Badge.kicad_sch]
2022-08-18 adding silk layer
    [BsidesKC-2022-Safe-Badge.kicad_sch]
2022-08-19 fixes
    Fixing silk, and adding headers
    [BsidesKC-2022-Safe-Badge-B_Cu.gbr, BsidesKC-2022-Safe-Badge-B_Mask.gbr, BsidesKC-2022-Safe-Badge-B_Silkscreen.gbr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]
2022-08-19 adding R
    [BsidesKC-2022-Safe-Badge.kicad_sch]
2022-08-19 Gerbers and a single trace move
    [BsidesKC-2022-Safe-Badge-B_Cu.gbr, BsidesKC-2022-Safe-Badge-B_Mask.gbr, BsidesKC-2022-Safe-Badge-B_Silkscreen.gbr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]
2022-08-20 Making China Happy with Back Mask
    [BsidesKC-2022-Safe-Badge-B_Cu.gbr, BsidesKC-2022-Safe-Badge-B_Mask.gbr, BsidesKC-2022-Safe-Badge-B_Silkscreen.gbr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]
2022-08-31 fixing rotatry messup
    [BsidesKC-2022-Safe-Badge.kicad_sch]
2022-09-02 Artwork Updates
    Added artwork/pretty files for each version of the badge
    Updated Moon SAO and added pretty files
    Created sample of the BsidesKC2022 shirt logo/poster
    [BsidesKC 2022 Poster - Simple.kicad_pcb, BsidesKC SAO - Moon.kicad_pcb, BsidesKC-2022-Safe-Badge - Badge Pirates.kicad_pcb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]
2022-09-02 encoder turns the lights
2022-09-02 versions and gerbers
    [BsidesKC-2022-Safe-Badge-B_Cu.gbr, BsidesKC-2022-Safe-Badge-B_Mask.gbr, BsidesKC-2022-Safe-Badge-B_Silkscreen.gbr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]
2022-09-02 improve encoder performance
    While spinning the encoded fast I was able to cause it to lock up repeatedly. I looked at the example code and noticed they had a way of detecting direction as a 1 or -1 and I decided to use that to increment or decrement the lit up number position. Also made a helper function for turning off all the lights, I think ideally we'd just turn off the last light instead of doing all of them but we can fix that later.
    [main.cpp]
2022-09-02 Gold SAO artwork/CAD
    Completed Gold vendor designs
    [Arista-TGS.kicad_pcb, Corelight SAO.kicad_pcb, Red Canary.kicad_pcb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]
2022-09-03 Village Badge
    [BsidesKC-2022-Safe-Badge - Village.kicad_pcb]
2022-09-03 village update
    [BsidesKC-2022-Safe-Badge - Village.kicad_pcb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]
2022-09-04 added alignment marks
    [BsidesKC-2022-Safe-Badge-B_Cu.gbr, BsidesKC-2022-Safe-Badge-B_Mask.gbr, BsidesKC-2022-Safe-Badge-B_Silkscreen.gbr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]
2022-09-04 add back in bling mode
    this does bling mode without using delays, it takes in the current run time and figures out if it should advance to the next part of the animation. broke input mode somehow but we should be able to figure that out.
    [main.cpp]
2022-09-04 button push works!
2022-09-05 reset userInput and inputPosition on transition back to bling mode and turn off all LEDs when transitioning to input mode
    [main.cpp]
2022-09-06 Sao Creations
    [Arista-TGS-B_Cu.gbr, Arista-TGS-B_Mask.gbr, Arista-TGS-B_Silkscreen.gbr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]
2022-09-06 move rotary switch over to pin.h
2022-09-06 Resized BsidesKC SAO
    [BsidesKC 2022 Poster - Simple.kicad_pcb]
2022-09-06 Soldering Village-Crew Badge
    [Soldering Crew Badge.kicad_pcb]
2022-09-06 Cutout eye for Soldering Village badge
2022-09-06 Update Soldering Crew Badge.svg
2022-09-07 Resized/Updated Soldering Village SAO
    [Soldering Crew Badge.kicad_pcb]
2022-09-07 Order Tracking Sheet
    [Badge Order Tracking.xlsx]
2022-09-07 soa and doc updates
    [Badge Order Tracking.xlsx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]
2022-09-07 BsidesKC 2022 Badge Schematic PCB
    [BsidesKC 2022 Badge Schematic.kicad_pcb]
2022-09-09 added pwm test
2022-09-09 fix rotary encoder turning by reverting pin.h and constant.h
    [main.cpp]
2022-09-10 Update Tracking
    [Badge Order Tracking.xlsx]
2022-09-16 Templates - WIP
    These are templates off of last years, I will update with current Costs and Pricing this weekend.
    [BSides22 Project Summary.xlsx, Bsides22 Pricing Sheet.xlsx]
2022-09-16 updates to Project Summary and Costs
    [BSides22 Project Summary.xlsx]
2022-09-18 use rotary button
2022-09-19 Update BsidesKC 2022 Badge Schematic.svg
2022-09-19 Added HTML BOM View
2022-09-23 Correct inverted LED
2022-09-23 low(er) power mode
2022-09-23 Show blink confimation when button is pressed
2022-09-23 confirmation flash on correct code entry
    [constants.hpp, main.cpp]
2022-09-23 Better handling on code errors and input reset triggers
    [hardware.cpp, main.cpp]
2022-09-26 doc update
    [BSides22 Project Summary.xlsx, Bsides22 Pricing Sheet.xlsx]
2022-09-26 Update BSides22 Project Summary.xlsx
    [BSides22 Project Summary.xlsx]
2022-11-09 Create BsidesKC Soldering Village Poster.svg
